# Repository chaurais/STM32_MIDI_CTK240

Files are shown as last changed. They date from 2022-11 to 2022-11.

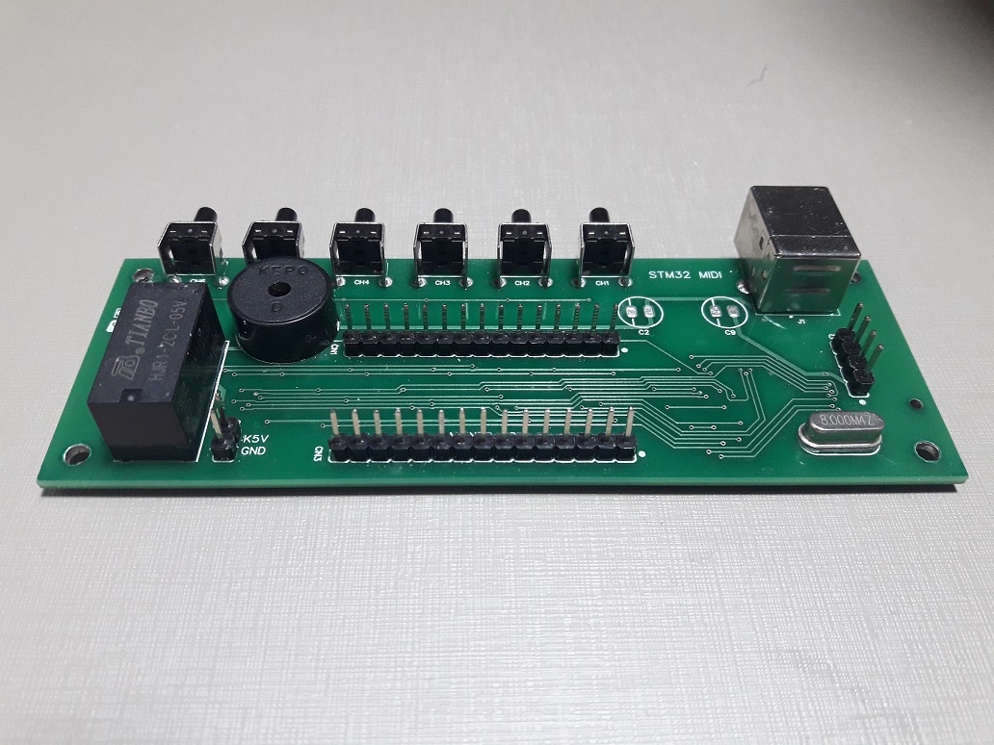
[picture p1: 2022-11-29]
Docs/20220116_143911.jpg

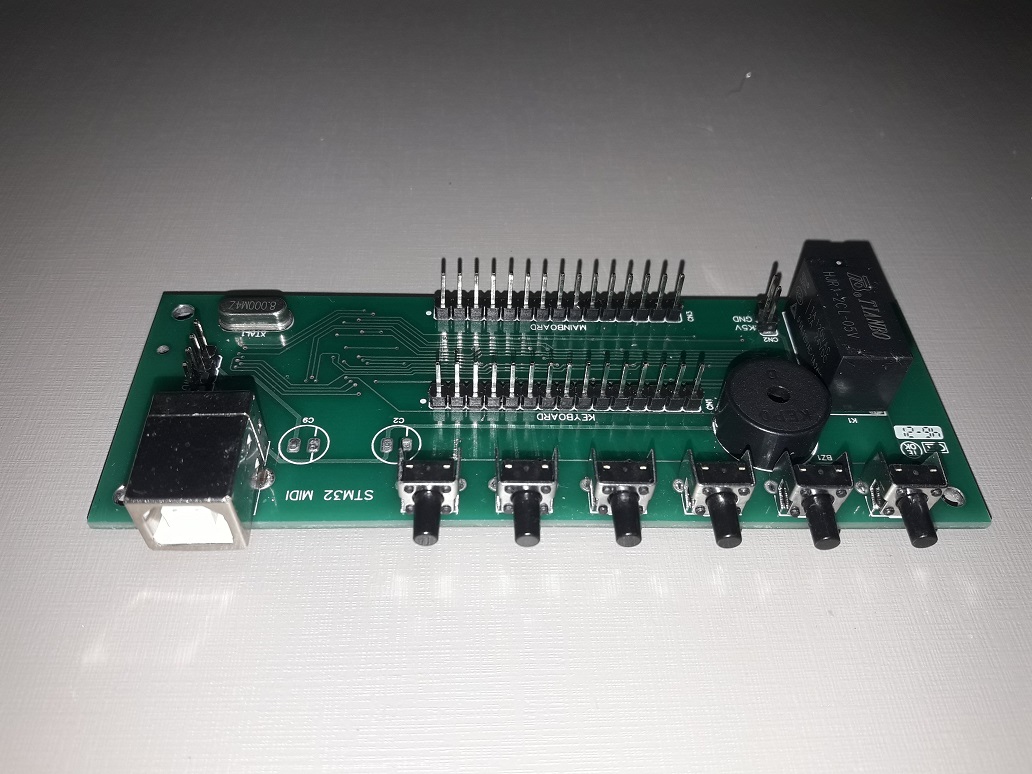
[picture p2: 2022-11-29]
Docs/20220116_143853.jpg

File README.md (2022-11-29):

# STM32_MIDI_CTK240

Based on https://github.com/abelykh0/stm32f103-midi
I used part of the code developed by "abelykh0" and implemented a scan routine for the keyboard of my Casio CTK240.
The circuit developed for the CTK240 has a multiplexer for the keyboard, which automatically switches the keyboard to the main board of the CTK240, when powered by the power supply or to the MIDI board, when powered by the USB port.
That way I can use the CTK240 in the original way, as a musical keyboard or use it as a MIDI controller.
As a MIDI controller, the keyboard sends Note ON and Note OFF commands and through six commands I can split the keyboard and select the octave and velocity of each part, independently. O teclado do Casio CTK240 não possui controle de velocidade.
Firmware compiled with STM32CubeIDE.

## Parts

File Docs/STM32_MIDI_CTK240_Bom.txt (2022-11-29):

RefDes                     	Name    	Value    
____________________________________________________________

BZ1                          	BUZZER_P    	            
C1, C4                       	CAP_0805    	20pF        
C2, C9                       	CAP_POL     	47uF        
C3, C5, C6, C7, C8, C10, C11 	CAP_0805    	100nF       
CH1                          	TACTIL4_90  	SHIFT       
CH2                          	TACTIL4_90  	SPLIT       
CH3                          	TACTIL4_90  	<OCT        
CH4                          	TACTIL4_90  	OCT>        
CH5                          	TACTIL4_90  	<VEL        
CH6                          	TACTIL4_90  	VEL>        
CN1, CN3                     	CONM15PIN   	            
CN2                          	SIP2        	            
CN4                          	SIP4        	            
D1, D2, D3, D4, D5, D6, D7   	DL4148      	DL4148      
J1                           	USB_Type_B  	Type B      
K1                           	ML2RC2      	            
Q1, Q2                       	NPN SMD     	            
R1, R3                       	RES_0805    	100k        
R2, R4, R5                   	RES_0805    	1k          
R6, R7                       	RES_0805    	22R         
R8                           	RES_0805    	1k5         
U1, U2, U3, U4, U5           	74HC4053    	74HC4053    
U6                           	LD1117-3V3  	LD1117-3V3  
U7                           	STM32F103C8 	STM32F103C8 
XTAL1                        	XTAL        	8MHZ

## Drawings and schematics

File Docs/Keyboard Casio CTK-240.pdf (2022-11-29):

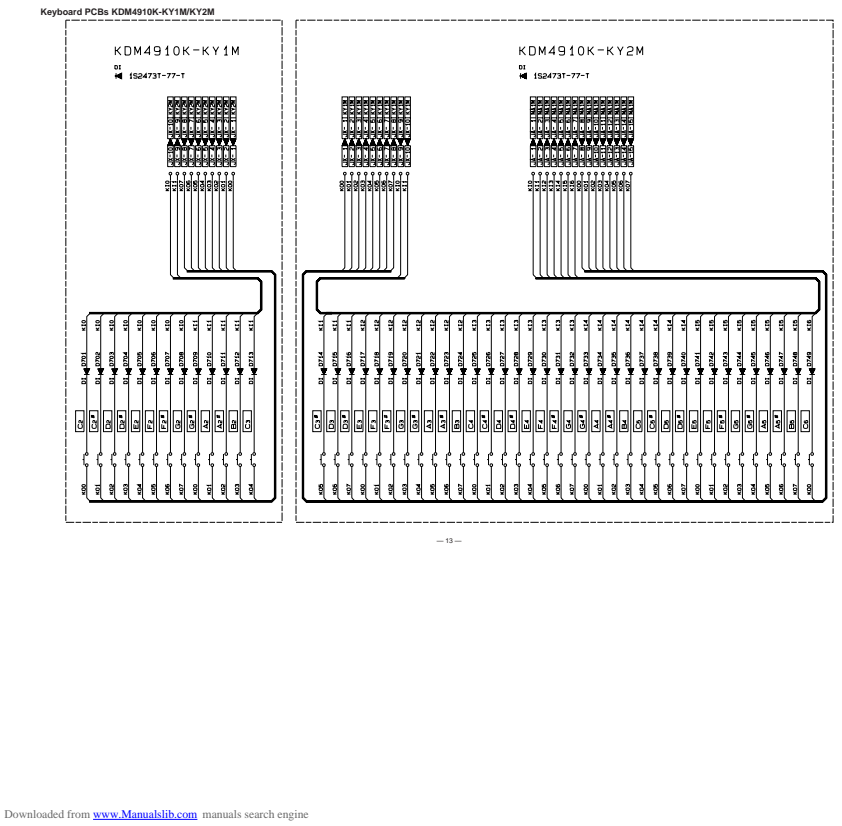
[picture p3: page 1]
Keyboard PCBs KDM4910K-KY1M/KY2M

Downloaded from www.Manualslib.com manuals search engine

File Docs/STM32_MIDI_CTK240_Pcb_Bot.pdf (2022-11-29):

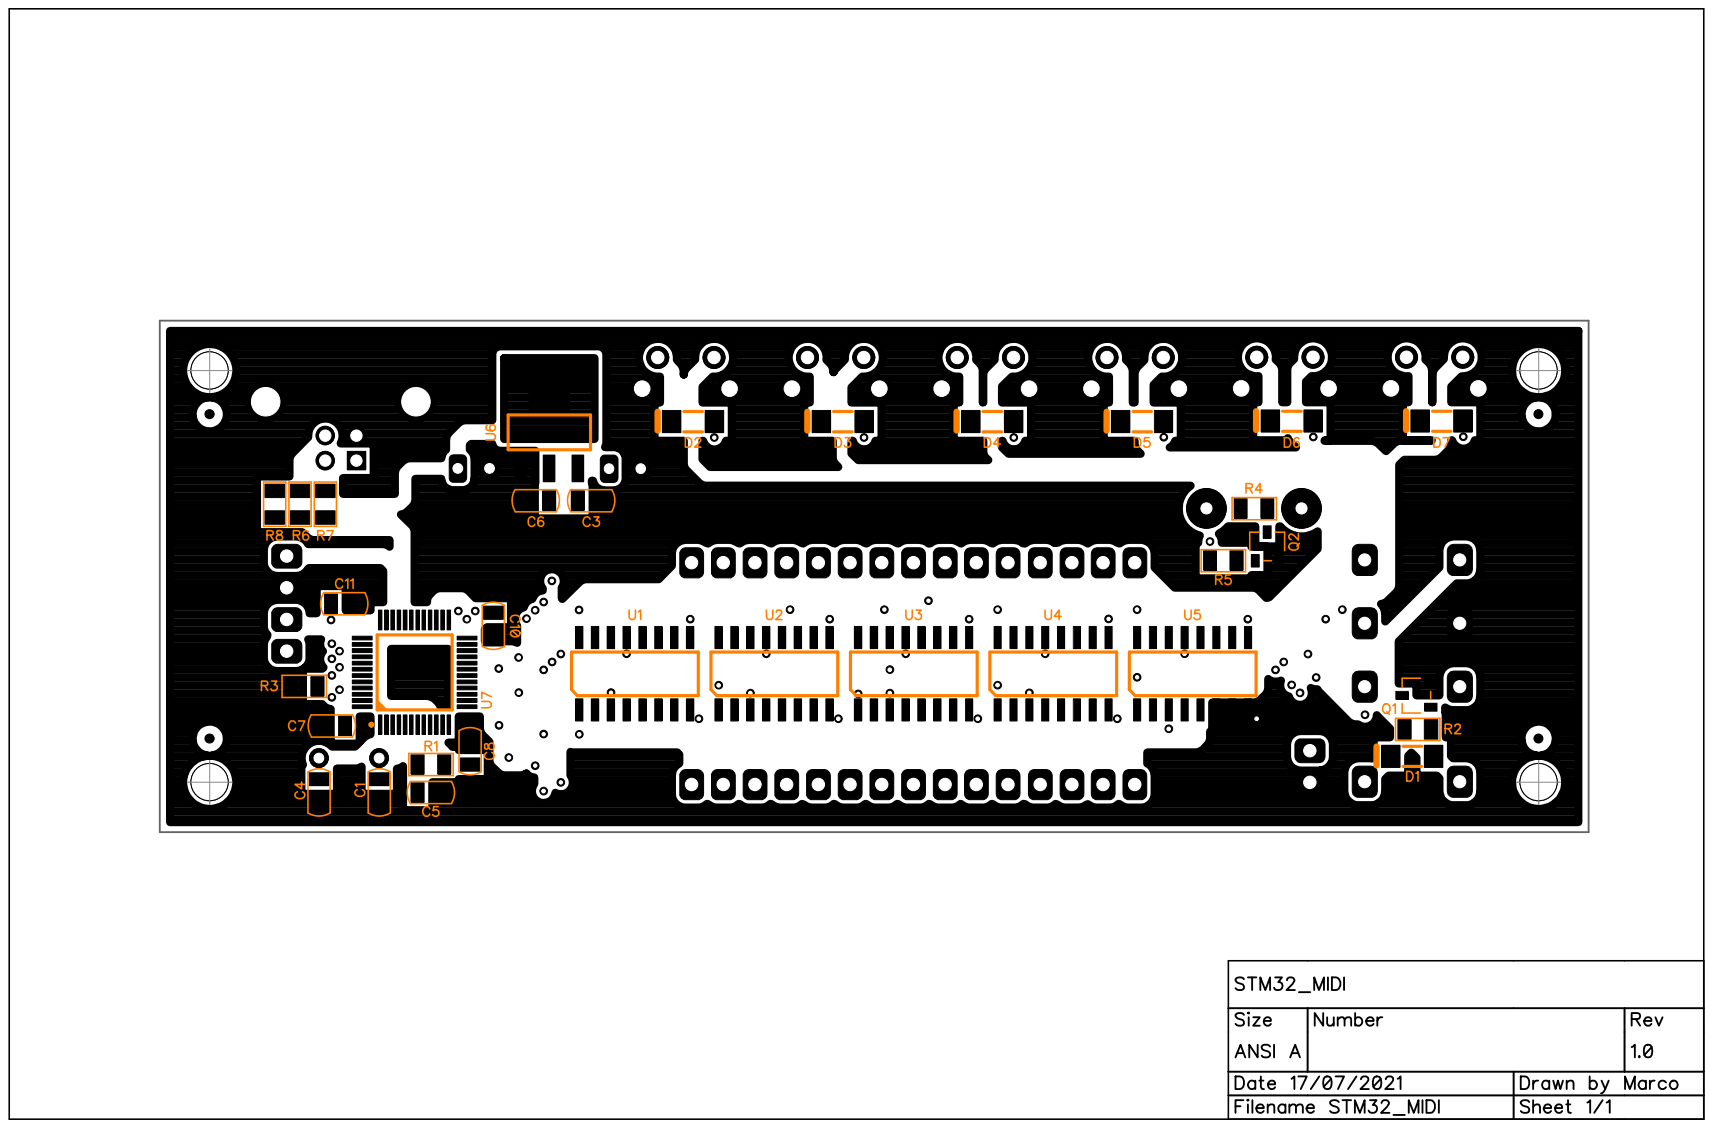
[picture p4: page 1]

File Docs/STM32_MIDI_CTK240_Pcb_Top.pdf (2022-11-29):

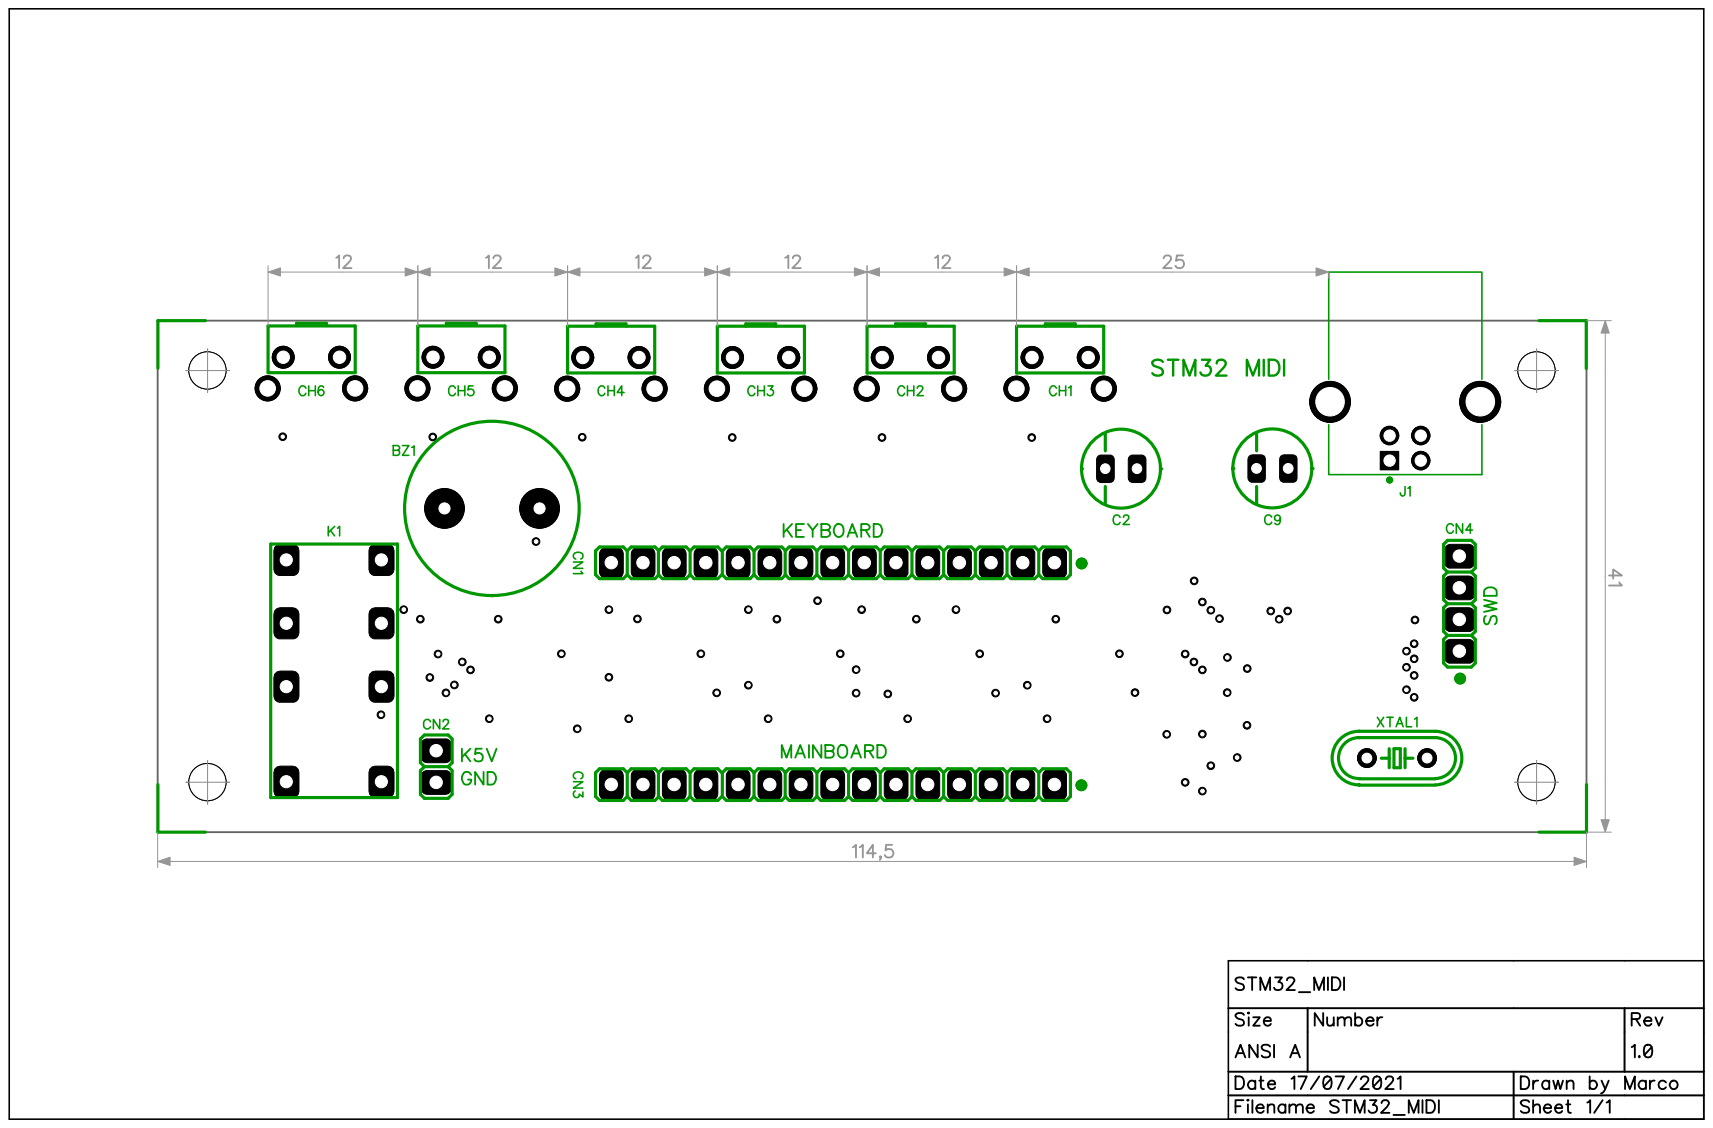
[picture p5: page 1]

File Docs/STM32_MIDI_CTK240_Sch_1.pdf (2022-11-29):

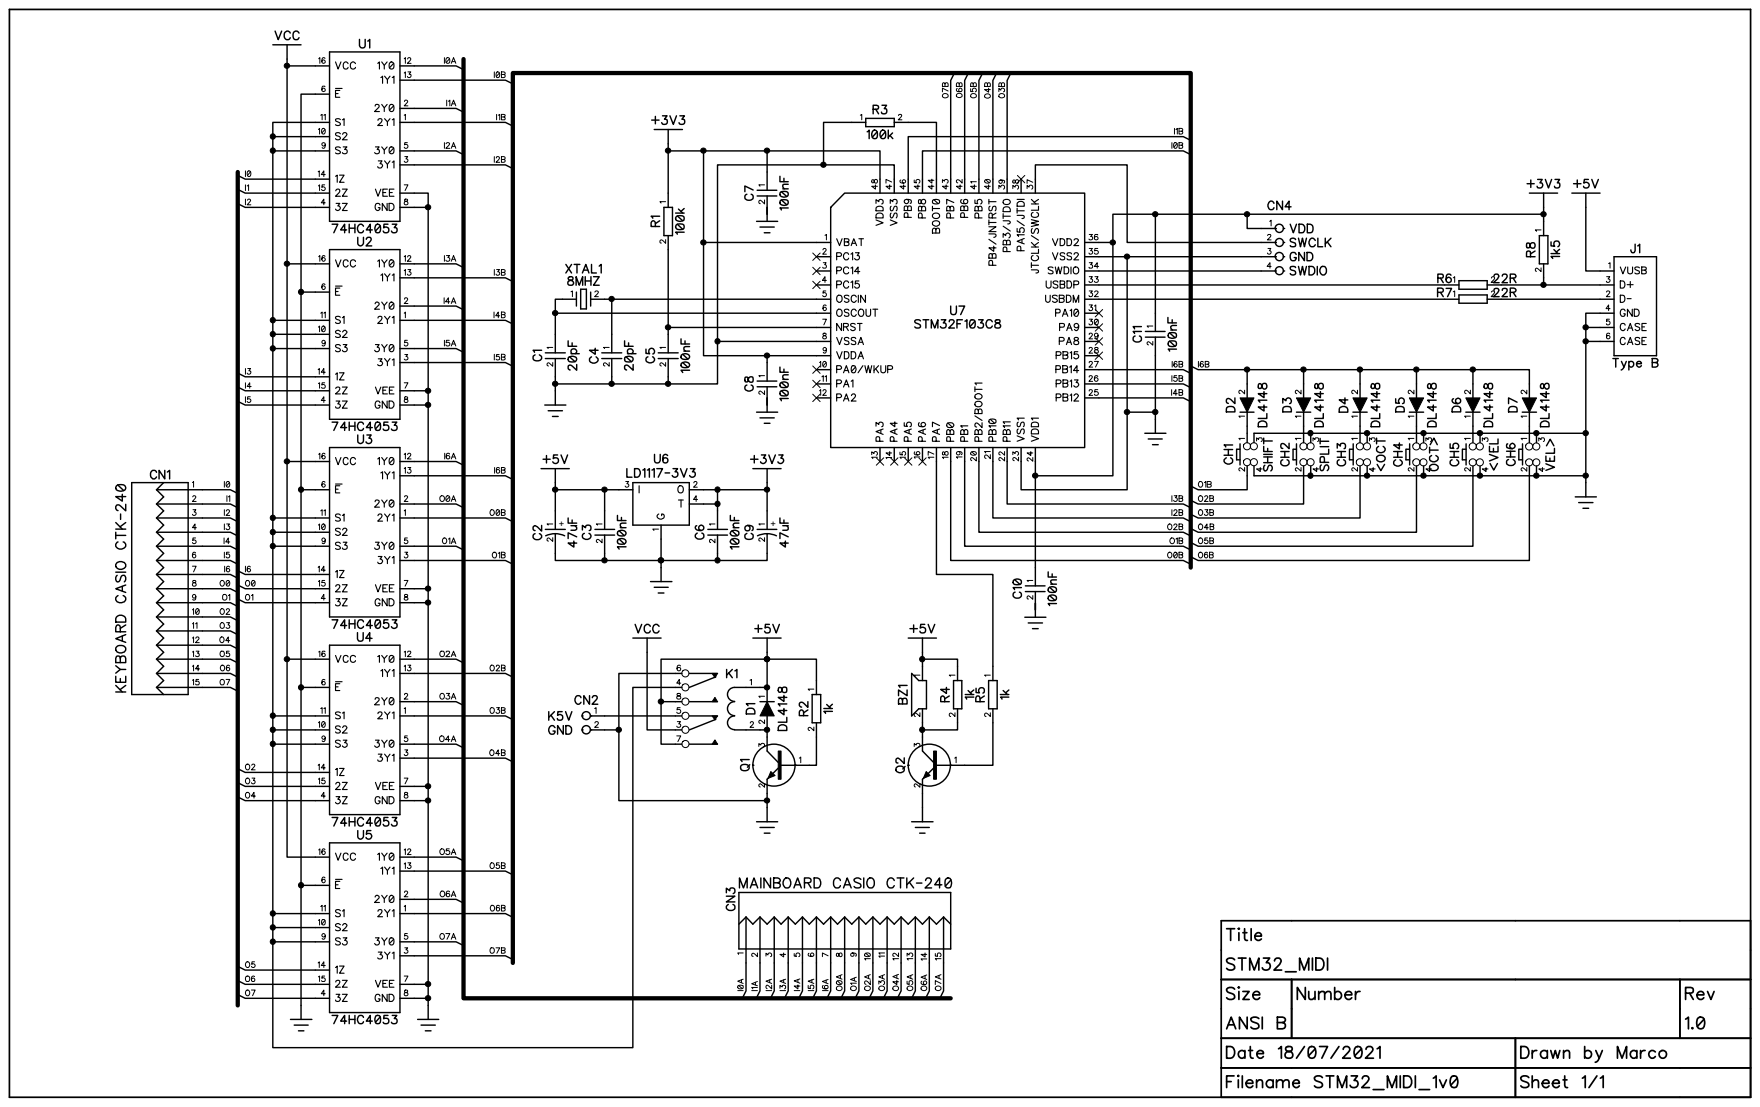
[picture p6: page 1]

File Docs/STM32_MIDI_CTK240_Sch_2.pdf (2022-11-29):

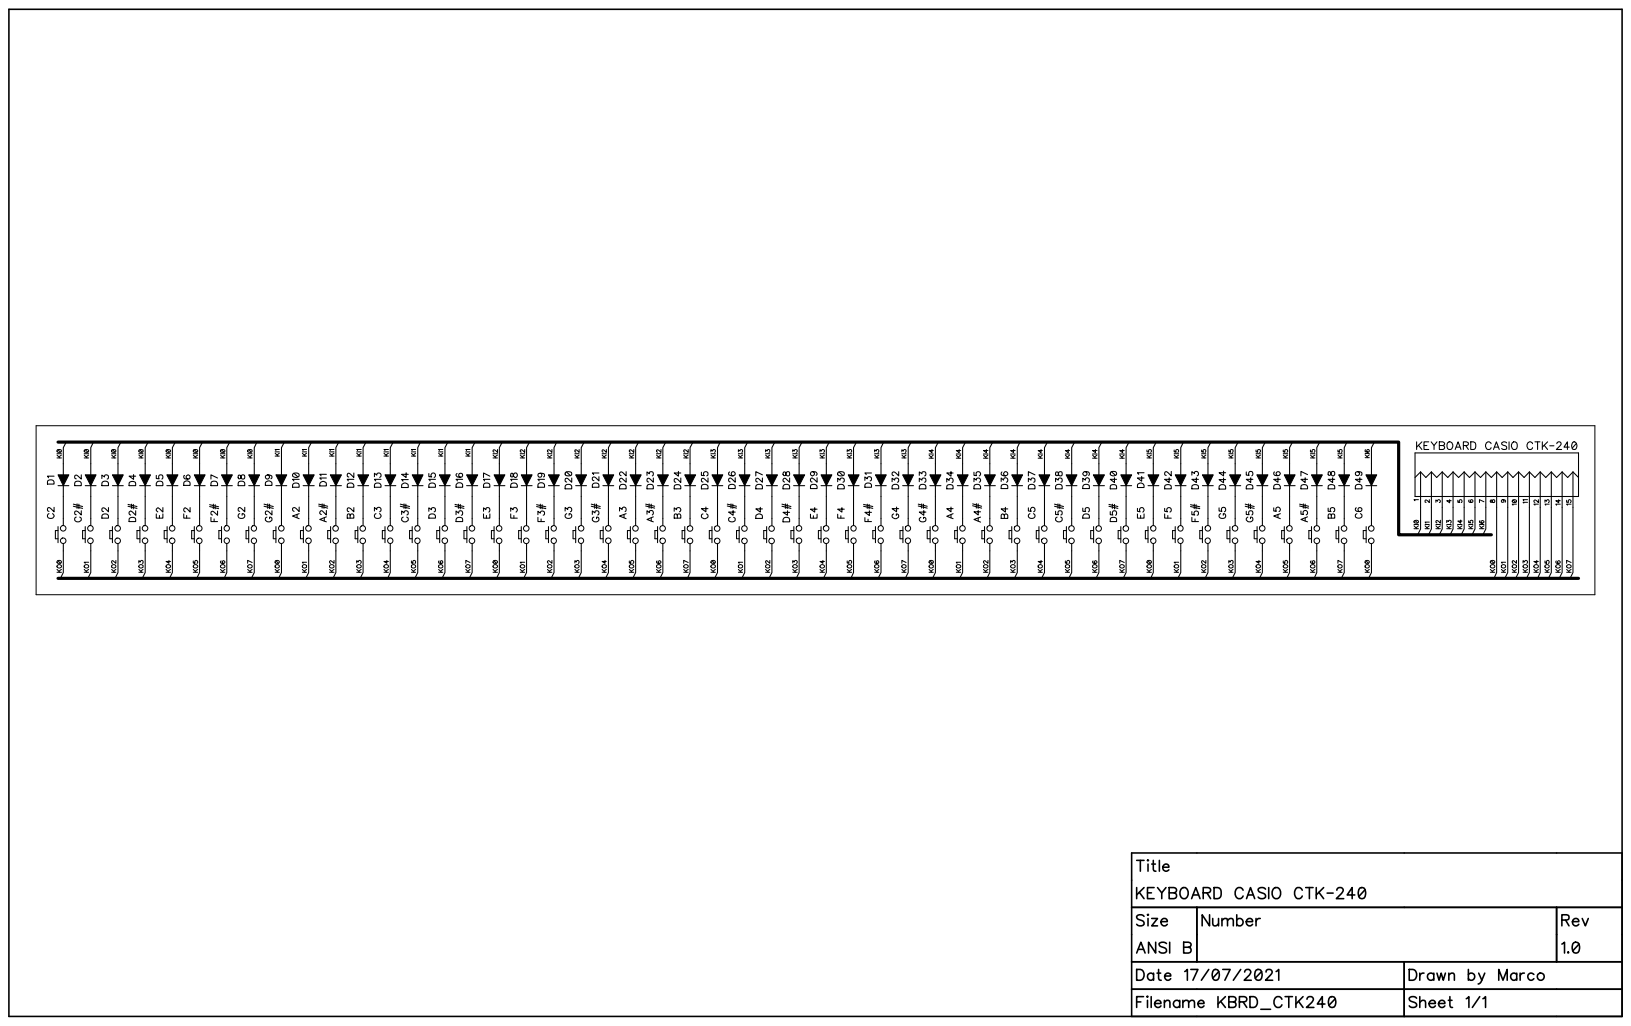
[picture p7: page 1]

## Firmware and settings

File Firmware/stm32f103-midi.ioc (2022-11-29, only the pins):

Mcu.UserName=STM32F103C8Tx
PA11.Signal=USB_DM
PA12.Signal=USB_DP
PA13.Signal=SYS_JTMS-SWDIO
PA14.Signal=SYS_JTCK-SWCLK
PA7.Signal=S_TIM3_CH2
PB0.Signal=GPIO_Output
PB1.Signal=GPIO_Output
PB10.Signal=GPIO_Input
PB11.Signal=GPIO_Input
PB12.Signal=GPIO_Input
PB13.Signal=GPIO_Input
PB14.Signal=GPIO_Input
PB2.Signal=GPIO_Output
PB3.Signal=GPIO_Output
PB4.Signal=GPIO_Output
PB5.Signal=GPIO_Output
PB6.Signal=GPIO_Output
PB7.Signal=GPIO_Output
PB8.Signal=GPIO_Input
PB9.Signal=GPIO_Input
PD0-OSC_IN.Signal=RCC_OSC_IN
PD1-OSC_OUT.Signal=RCC_OSC_OUT

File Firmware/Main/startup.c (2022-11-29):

#include "startup.h"
#include <string.h>
#include <stdint.h>
#include "Sound/midiMessage.h"

TIM_HandleTypeDef htim3;
static uint8_t FirstNote0 = 48; //Nota C2
static uint8_t FirstNote1 = 48; //Nota C2
static uint64_t KeypadState = 0; //estado do teclado
static uint64_t NoteBit; //posição do estado da tecla
static uint8_t Note = 0; //nota (0 a 48 -> 49 teclas)
static uint8_t SNote = 48; //SNote = 0: somente canal 1, SNote = 48: somente canal 0
static uint8_t Velocit = 96; //velocidade da nota (varia de 64 a 127)
static uint8_t KOut = 0; //saída para varredura do teclado
static uint8_t KInp = 0; //entrada para varredura do teclado
static uint8_t Split = 0; //divisão do teclado: 0 - não dividido, 1 - dividido
static uint8_t Shift = 0; //shift: 0 - destivado, 1 - ativado

void initialize()
{
}

void setup()
{
}

void keypad_scan()
{
	for(KOut = 0; KOut < 8; KOut++)
	{
		//coloca todas as saídas em nível 1
		HAL_GPIO_WritePin(GPIOB, GPIO_PIN_0 | GPIO_PIN_1 | GPIO_PIN_2 | GPIO_PIN_3 \
				| GPIO_PIN_4 | GPIO_PIN_5 | GPIO_PIN_6 | GPIO_PIN_7, GPIO_PIN_SET);
		switch(KOut) //coloca uma saída em nível 0
		{
			case 0:
				HAL_GPIO_WritePin(GPIOB, GPIO_PIN_0, GPIO_PIN_RESET);
				break;
			case 1:
				HAL_GPIO_WritePin(GPIOB, GPIO_PIN_1, GPIO_PIN_RESET);
				break;
			case 2:
				HAL_GPIO_WritePin(GPIOB, GPIO_PIN_2, GPIO_PIN_RESET);
				break;
			case 3:
				HAL_GPIO_WritePin(GPIOB, GPIO_PIN_3, GPIO_PIN_RESET);
				break;
			case 4:
				HAL_GPIO_WritePin(GPIOB, GPIO_PIN_4, GPIO_PIN_RESET);
				break;
			case 5:
				HAL_GPIO_WritePin(GPIOB, GPIO_PIN_5, GPIO_PIN_RESET);
				break;
			case 6:
				HAL_GPIO_WritePin(GPIOB, GPIO_PIN_6, GPIO_PIN_RESET);
				break;
			case 7:
				HAL_GPIO_WritePin(GPIOB, GPIO_PIN_7, GPIO_PIN_RESET);
				break;
		}
		for(KInp = 0; KInp < 7; KInp++) //testa o estado de todas as entradas
		{
			Note = (KInp * 8) + KOut; //obtem a nota
			NoteBit = 1;
			NoteBit <<= Note;
			switch(KInp)
			{
				case 0:
					if(HAL_GPIO_ReadPin(GPIOB, GPIO_PIN_8) == GPIO_PIN_RESET) key_pressed(); //tecla pressionada
					else key_unpressed(); //tecla não pressionada
					break;
				case 1:
					if(HAL_GPIO_ReadPin(GPIOB, GPIO_PIN_9) == GPIO_PIN_RESET) key_pressed(); //tecla pressionada
					else key_unpressed(); //tecla não pressionada
					break;
				case 2:
					if(HAL_GPIO_ReadPin(GPIOB, GPIO_PIN_10) == GPIO_PIN_RESET) key_pressed(); //tecla pressionada
					else key_unpressed(); //tecla não pressionada
					break;
				case 3:
					if(HAL_GPIO_ReadPin(GPIOB, GPIO_PIN_11) == GPIO_PIN_RESET) key_pressed(); //tecla pressionada
					else key_unpressed(); //tecla não pressionada
					break;
				case 4:
					if(HAL_GPIO_ReadPin(GPIOB, GPIO_PIN_12) == GPIO_PIN_RESET) key_pressed(); //tecla pressionada
					else key_unpressed(); //tecla não pressionada
					break;
				case 5:
					if(HAL_GPIO_ReadPin(GPIOB, GPIO_PIN_13) == GPIO_PIN_RESET) key_pressed(); //tecla pressionada
					else key_unpressed(); //tecla não pressionada
					break;
				case 6:
					if(HAL_GPIO_ReadPin(GPIOB, GPIO_PIN_14) == GPIO_PIN_RESET) key_pressed(); //tecla pressionada
					else key_unpressed(); //tecla não pressionada
					break;
			}
		}
		HAL_Delay(1);
	}
}

void key_pressed()
{
	if(!(KeypadState & NoteBit)) //estava pressionada?
	{ //não
		KeypadState |= NoteBit; //sinaliza tecla pressionada
		if(Note >= 0 && Note <= 48) //nota dentro do intervalo válido?
		{ //sim
			if(Split == 1) //Split ativado?
			{ //sim
				SNote = Note; //define a divisão do teclado
				if(SNote == 48) beep(1, 100,100); //1 bip curto
				else if(SNote == 0) beep(2, 100, 100); //2 bips curtos
				else  beep(3, 100, 100); //3 bips curtos
			}
			else
			{ //não, toca a nota pressionada
				if(SNote == 48) //somente canal 0?
				{ // sim
					midiMessage(MIDI_NOTE_ON, 0, FirstNote0 + Note, Velocit); //envia mensagem
				}
				else if(SNote == 0) //somente canal 1?
				{ //sim
					midiMessage(MIDI_NOTE_ON, 1, FirstNote1 + Note, Velocit); //envia mensagem
				}
				else
				{ //canal 0 e canal 1 (teclado dividido
					if(Note < SNote) //teclas do canal 0?
					{ //sim
						midiMessage(MIDI_NOTE_ON, 0, FirstNote0 + Note, Velocit); //envia mensagem
					}
					else
					{ //não, teclas do canal 1
						midiMessage(MIDI_NOTE_ON, 1, FirstNote1 + Note, Velocit); //envia mensagem
					}
				}
			}
		}
		else if(Note == 49) //função SHIFT?
		{ //sim
			Shift = 1; //ativa
		}
		else if(Note == 50) //função SPLIT?
		{ //sim
			Split = 1; //ativa
		}
		else if(Note == 51) //função <OCT?
		{ //sim
			if(Shift == 1) //Shif ativado?
			{ //sim
				FirstNote1 += 12; //desloca uma oitava para direita
				if(FirstNote1 > 72)
				{
					FirstNote1 = 72; //limita em C4
					beep(1, 500, 100); //1 bip longo
				}
				else beep(1, 100, 100); //um bip curto
			}
			else
			{ //não
				FirstNote0 += 12; //desloca uma oitava para direita
				if(FirstNote0 > 72)
				{
					FirstNote0 = 72; //limita em C4
					beep(1, 500, 100); //1 bip longo
				}
				else beep(1, 100, 100); //um bip curto
			}
		}
		else if(Note == 52) //função OCT>?
		{ //sim
			if(Shift == 1) //Shif ativado?
			{ //sim
				FirstNote1 -= 12; //desloca uma oitava para esquerda
				if(FirstNote1 < 24)
				{
					FirstNote1 = 24; //limita em C0
					beep(1, 500, 100); //1 bip longo
				}
				else beep(1, 100, 100); //um bip curto
			}
			else
			{ //não
				FirstNote0 -= 12; //desloca uma oitava para esquerda
				if(FirstNote0 < 24)
				{
					FirstNote0 = 24; //limita em C0
					beep(1, 500, 100); //1 bip longo
				}
				else beep(1, 100, 100); //um bip curto
			}
		}
		else if(Note == 53) //função <VEL?
		{ //sim
			if(Velocit == 127) Velocit = 128; //ajusta para subtrair
			if(Velocit -= 8); //diminui a velocidade
			if(Velocit < 64)
			{
				Velocit = 64; //limita em 64
				beep(1, 500, 100); //1 bip longo
			}
			else beep(1, 100, 100); //um bip curto
		}
		else if(Note == 54) //função VEL>?
		{ //sim
			Velocit += 8; //aumenta a velocidade
			if(Velocit > 127)
			{
				Velocit = 127; //limita em 127
				beep(1, 500, 100); //1 bip longo
			}
			else beep(1, 100, 100); //um bip curto
		}
	}
}
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
